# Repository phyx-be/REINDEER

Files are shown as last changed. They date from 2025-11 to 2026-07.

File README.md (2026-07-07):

# REINDEER
Christmas themed solder kit in the shape of Rudolph the Red-Nosed reindeer

<iframe src="https://lectronz.com/products/reindeer-solder-kit/embed?layout=horizontal&color=ff4100" style="width:100%;max-width:480px;height:180px;border:0" loading="lazy" title="Reindeer Solder Kit on Lectronz"></iframe>

## Design
Together with Fraincois Janssens we designed this Holiday themed solder kit. The electronics are basic, just a blinking red LED, a CR2032 battery and a small switch. Once we finally get a hold  of the UM66T-01L "Jingle Bells" tone generator, we can start offering the more advanced version of the kit which adds a buzzer and said tone generator.

## REV 00
Revision 00 was a dry run test for the mechanical fit and component placement.

## REV 01 
The production revision is 01 and has solder pads to fix the legs and antlers.

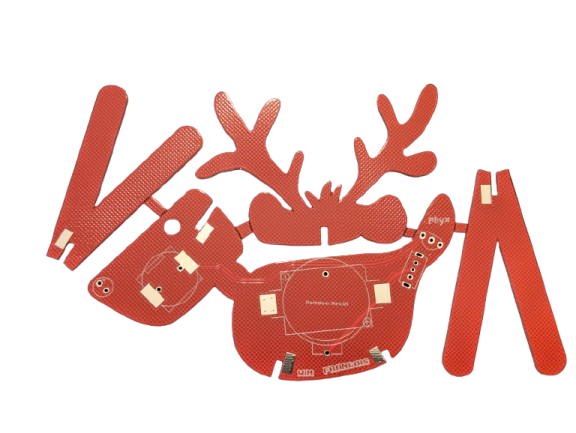
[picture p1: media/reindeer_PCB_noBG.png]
Bare PCB front


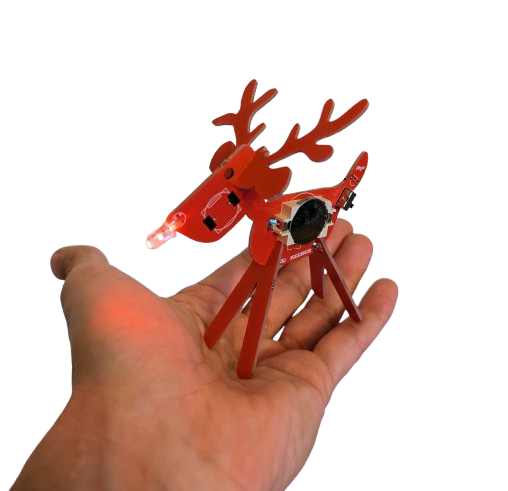
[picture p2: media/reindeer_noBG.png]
Assembled PCB


## Assembly instructions
- carefully depanelize the PCB by bending the parts, use pliers to remove the small pieces connecting the PCBs together
- optionally file or sand the rough edges
- pay attention to the orientation of the battery holder and the LED
- bend the LED leads and solder it in place
- once all parts are soldered, do a dry fit of the parts to ensure proper installation
- soldering the mechanical joints on one side first will allow you to make easy corrections when it's not perfectly perpendicular

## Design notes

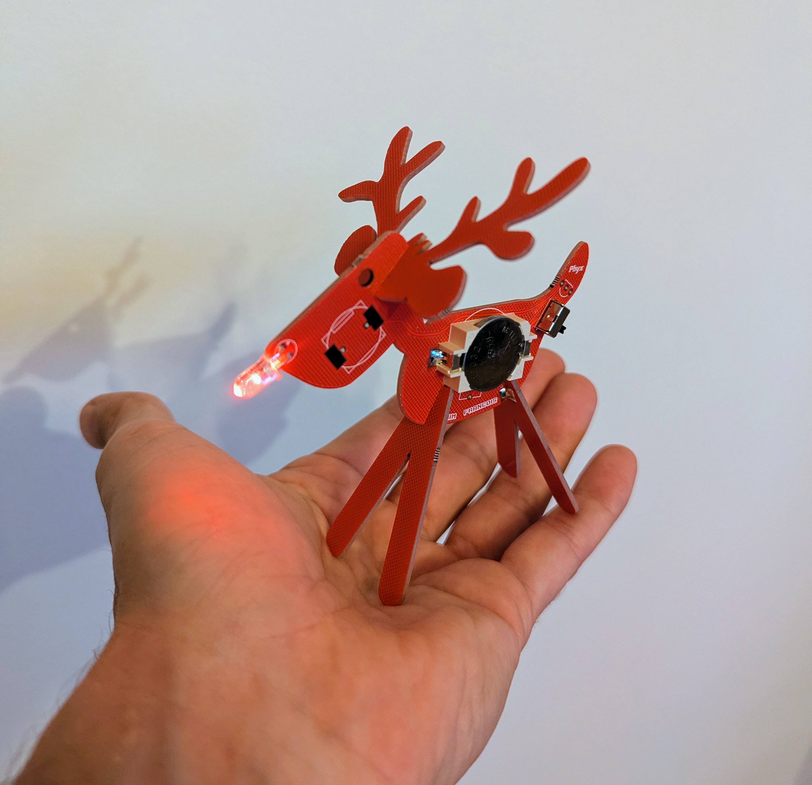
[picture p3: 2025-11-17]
media/reindeer.jpg

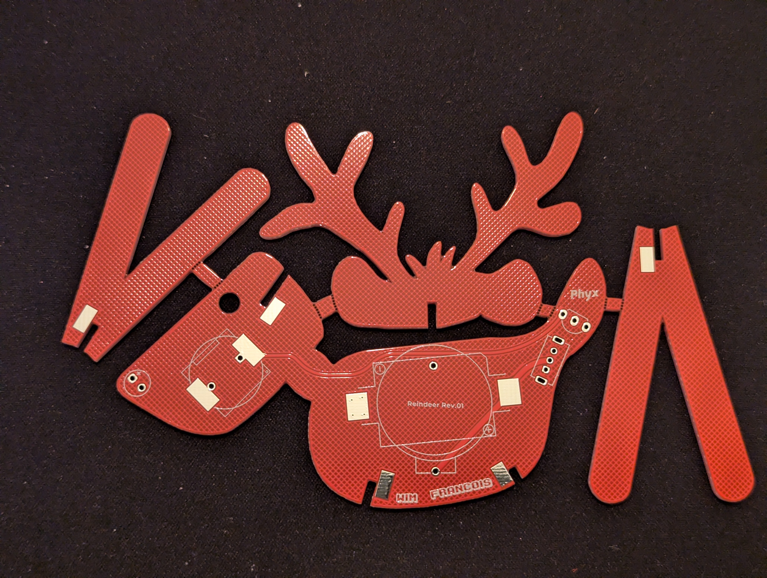
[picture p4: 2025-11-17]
media/reindeer_PCB.jpg

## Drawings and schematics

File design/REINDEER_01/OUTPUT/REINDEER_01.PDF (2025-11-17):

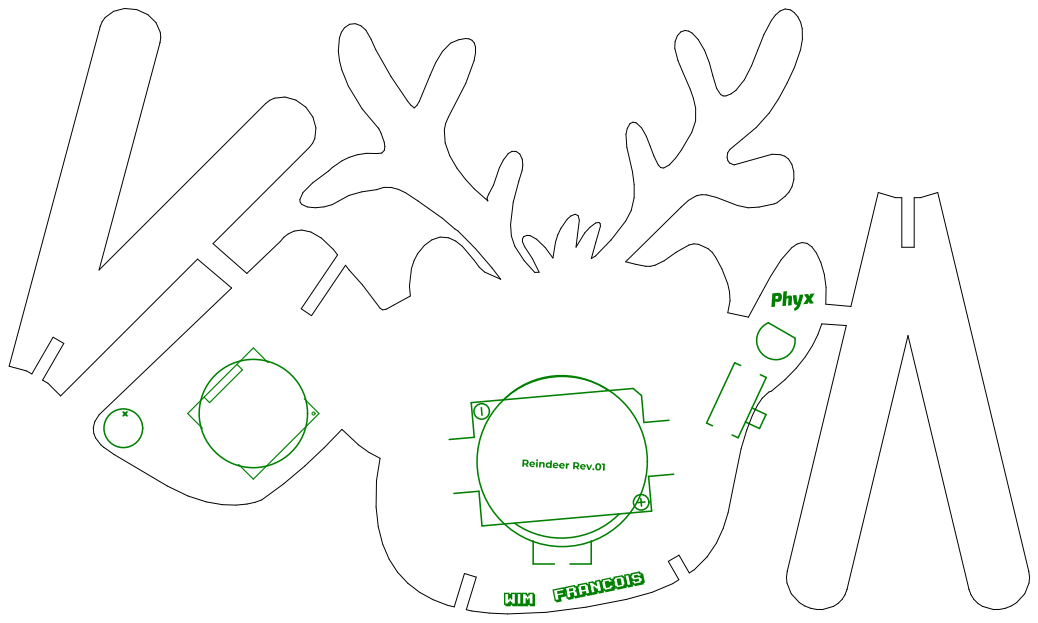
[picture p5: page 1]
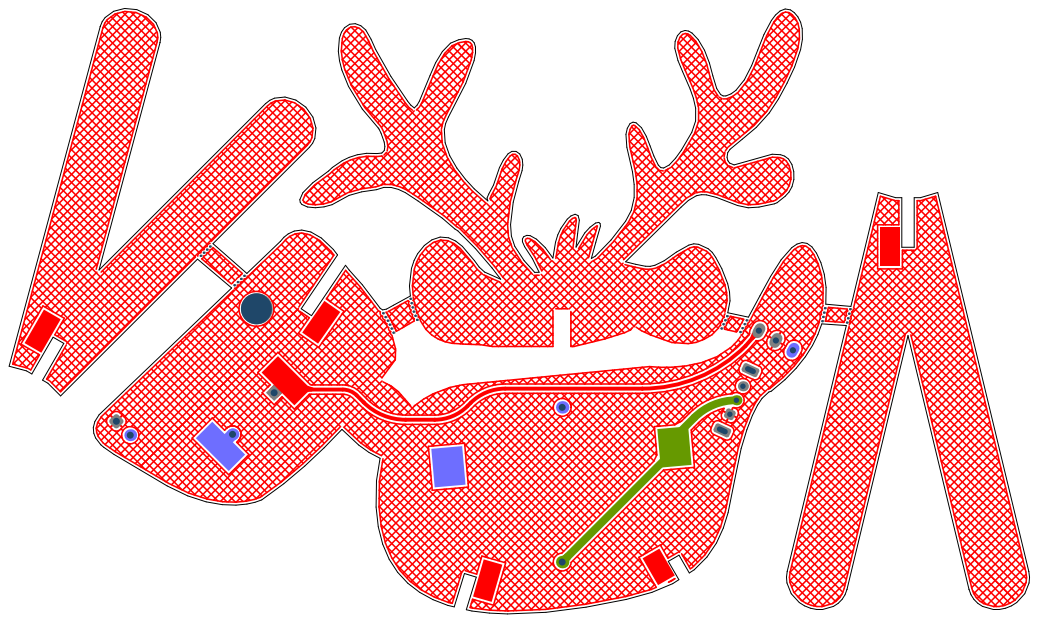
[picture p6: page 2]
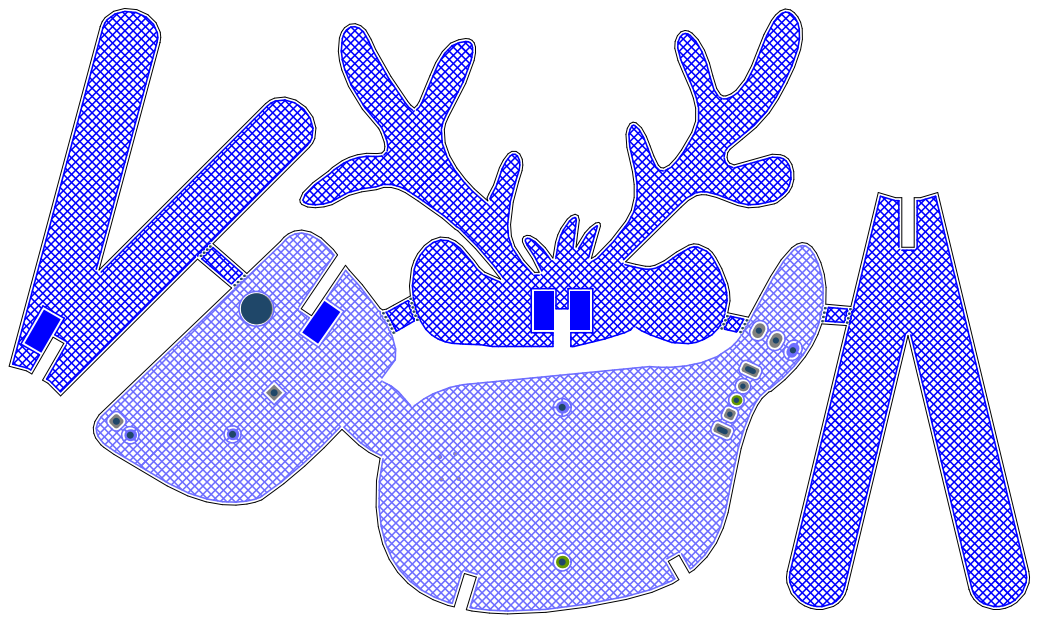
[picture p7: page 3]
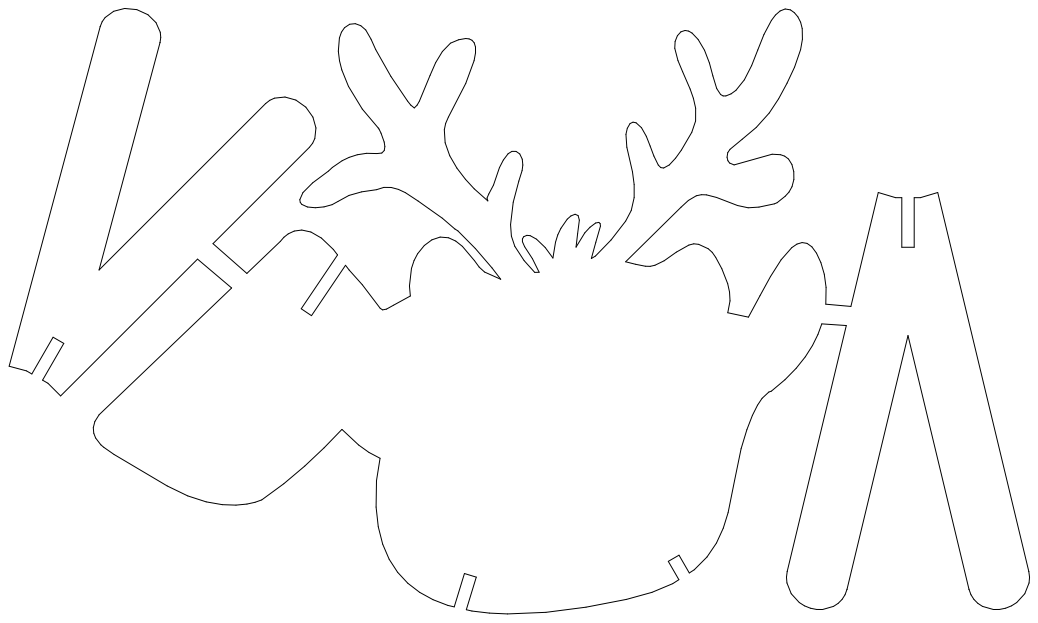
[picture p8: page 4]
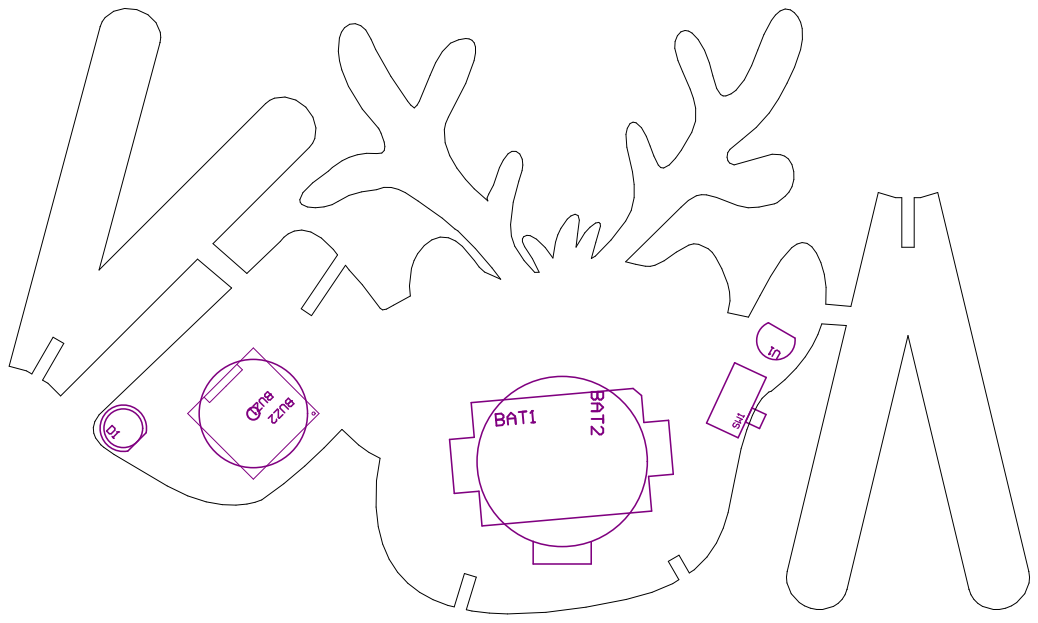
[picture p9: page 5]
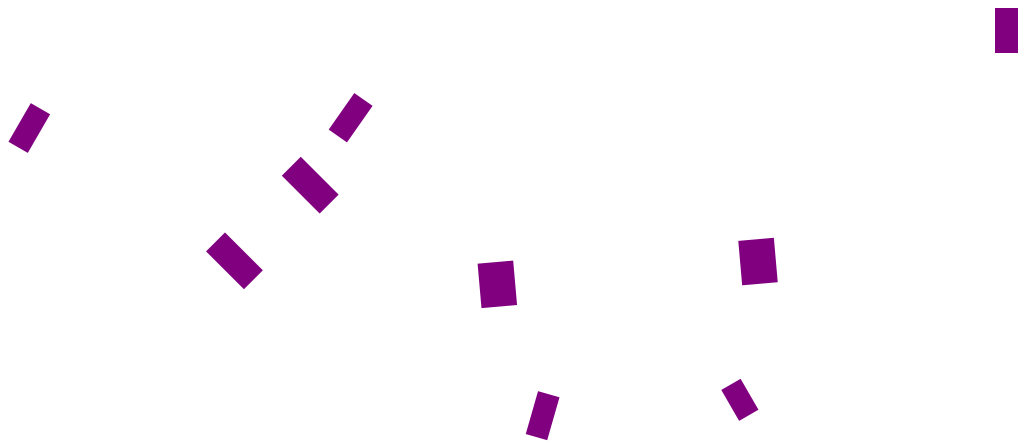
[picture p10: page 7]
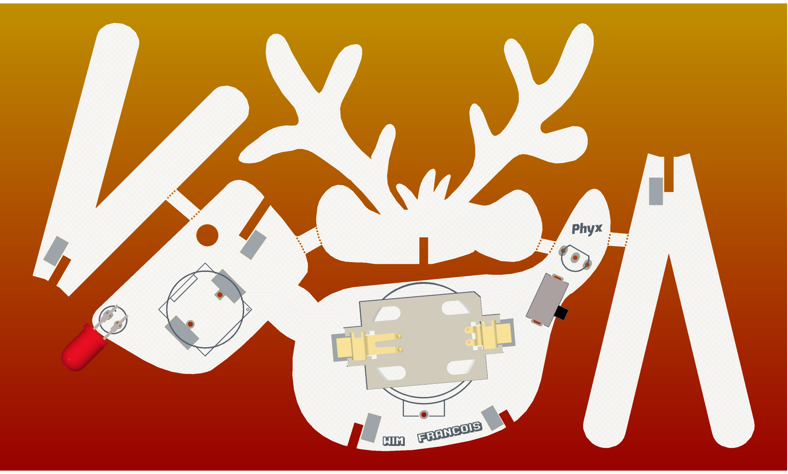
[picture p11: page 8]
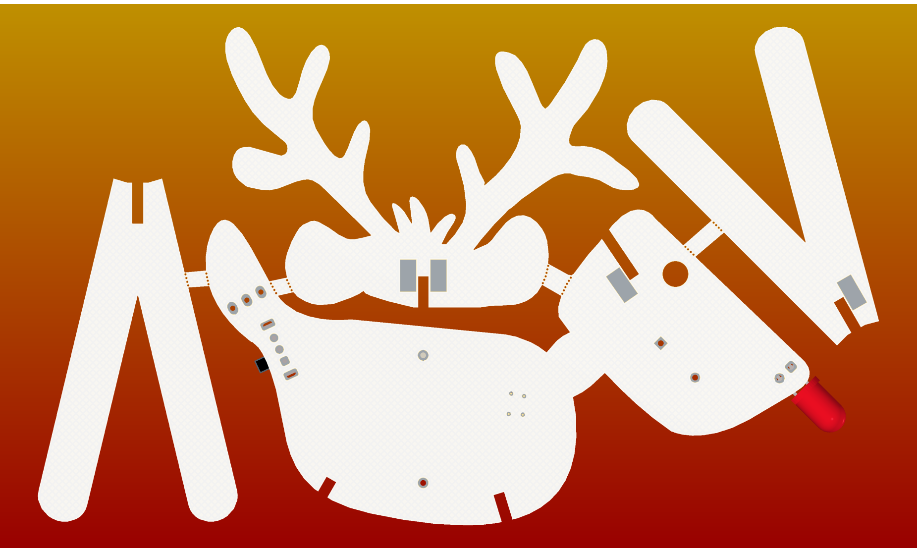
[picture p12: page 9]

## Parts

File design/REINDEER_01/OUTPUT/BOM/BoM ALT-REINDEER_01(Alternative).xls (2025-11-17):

Bill of Materials |  |  | Reindeer
Project: |  | REINDEER_01.PrjPcb
Revision: |  | 01
Variant: |  | Alternative
Creation Date: | 01/11/2025 | 22:29
Print Date: | 2025-11-01 | 22:29:32
Footprint | Comment | LibRef | Designator | Value | Description | Supplier 1 | Supplier Part Number 1 | Supplier 2 | Supplier Part Number 2 | Supplier 3 | Supplier Part Number 3 | Quantity
BAT_CR2032_China | CR2032 Battery Holder | BAT 20mm Coin Cell Holder Generic | BAT2 | CR2032 | BAT 20mm Coin Cell Holder Generic | LCSC | C5239862 | LCSC | C70376 |  |  | 1
CUI_CEP-1162 | 14x14x7mm Piezo Buzzer Transducer 80dB | BUZ CUI CEP-1162 | BUZ2 | CMT-1203-SMT | BUZ CUI CEP-1162 | Digi-key | 102-1134-ND | LCSC | C360604 |  |  | 1
LED_5MM_RD | 5mm IR LED, 940nm, 100mA, 1.35V, 25Deg | LED IR 5mm TSAL6400 | D1 | TSAL6400 | LED IR 5mm TSAL6400 | Farnell | 3152868 | LCSC | C264290 |  |  | 1
SK-12D07 | mini Switch 1 pole double throw right angle | SW 1P2T micro RA SK-12D07 | SW1 | SK-12D07 | SW 1P2T micro RA SK-12D07 | LCSC | C22383479 | LCSC | C521448 |  |  | 1
TO-92A_WIDE | UM66T - Fur Elise | SOUND UM66T-19L | U1 | UM66T-19L | SOUND UM66T-19L | LCSC | C136140 |  |  |  |  | 1
 |  |  |  |  |  |  |  |  |  |  |  | 5
Approved |  | Notes

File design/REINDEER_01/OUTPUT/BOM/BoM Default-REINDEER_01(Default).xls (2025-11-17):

Bill of Materials |  |  | Reindeer
Project: |  | REINDEER_01.PrjPcb
Revision: |  | 01
Variant: |  | Default
Creation Date: | 01/11/2025 | 22:29
Print Date: | 2025-11-01 | 22:29:36
Footprint | Comment | LibRef | Designator | Value | Description | Supplier 1 | Supplier Part Number 1 | Supplier 2 | Supplier Part Number 2 | Supplier 3 | Supplier Part Number 3 | Quantity
BAT_CR2032_KEY_1060 | CR2032 SMD Battery Holder | BAT # 20mm Coin Cell Holder Keystone 1060 | BAT1 | CR2032 | BAT # 20mm Coin Cell Holder Keystone 1060 | Digi-key | 36-1060-ND | LCSC | C70377 |  |  | 1
LED_5MM_RD | 5mm IR LED, 940nm, 100mA, 1.35V, 25Deg | LED IR 5mm TSAL6400 | D1 | TSAL6400 | LED IR 5mm TSAL6400 | Farnell | 3152868 | LCSC | C264290 |  |  | 1
SK-12D07 | mini Switch 1 pole double throw right angle | SW 1P2T micro RA SK-12D07 | SW1 | SK-12D07 | SW 1P2T micro RA SK-12D07 | LCSC | C22383479 | LCSC | C521448 |  |  | 1
 |  |  |  |  |  |  |  |  |  |  |  | 3
Approved |  | Notes
